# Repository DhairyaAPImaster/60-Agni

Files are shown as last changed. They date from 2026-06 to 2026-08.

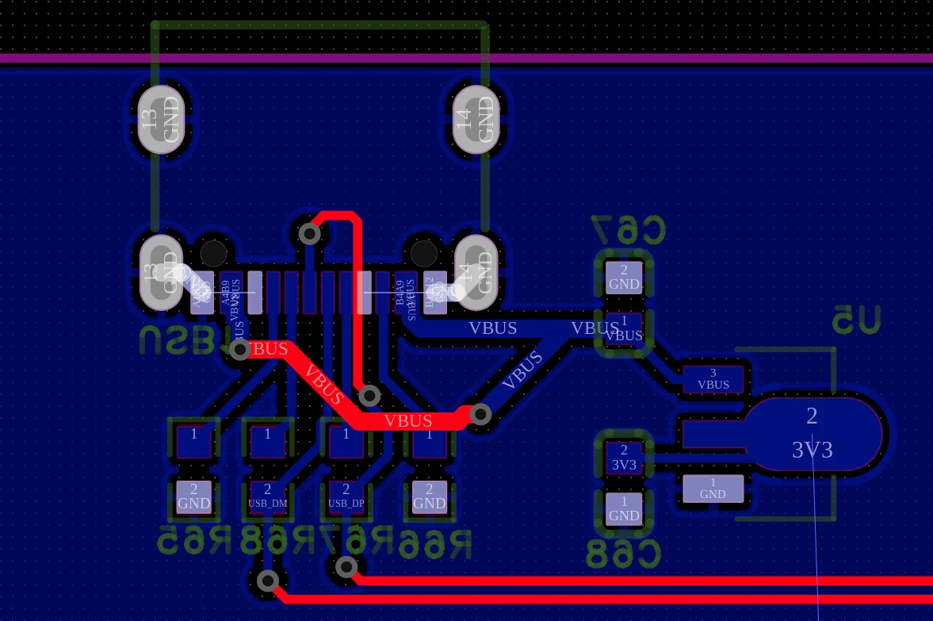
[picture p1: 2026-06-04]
Pics/image (3).webp

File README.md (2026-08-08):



***OSHWLAB Viewing link --->  https://oshwlab.com/dhairyak/project_nxljfiwq***

# Agni - the 60% keyboard
### by Dhairya

## About The Keyboard

**Agni is a custom 60% keyboard i have been working on for a few days. It is wired and connects to the laptop via USB-C. It also has an OLED on the top right corner to display data such as time, keyboard settings, etc.**

## Features 

- **60% default keyboard layout** - I chose this as it wouldf allow me to type easily and faster withought having to move my hand a lot.
- **Powered by a RP2040 at its core** - This runs the software required and allows the keyboard signals to be understood by the computer. It also runs the software to control the RGB lights and the OLED screen. 
- **Individual RGB lights for each Key** - So i added individual LED lights under each switch to give it better control to the lighting.

## Repo Structure 

- `src/` - source files for PCB and CAD
- `src/easyeda/` - EasyEDA source files
  - `src/easyeda/keyboard plate/` - src files for the keybard plate PCB
- `src/freecad/` - mechanical CAD sources
`production/` - **for fabrication outputs**
- `production/Keyboard plate PCB/` - PCB fabrication files for the keyboard plate
- `production/Main Keyboard PCB/` - PCB fabrication files for main keyboard PCB  (Gerbers, BOM, Pick & Place)
- `production/cad/` - 3D printing files
- `production/keyboard plate pcb/` -  Plate PCB Gerbers 
- `pics/` - images used in the README and documentation
- `firmware` - KMK firmware for the keyboard

## Schematic






## PCB 











## CAD





- ***Required 3d Printed part***



## How to replicate it (making it yourself) 

***Here are the steps to make this for yourself-***

- - ***ORDERING THE PCB***

- Step 1 - Basically Just Clone or downlaod this repo from github. U can do this by either going to the code button on this repo page and pressing download Zip or u can clone this Repo Or you can go to the Releases on this repo and download the Zip File there too (the fastest way to download is like just going to code and pressing download Zip Or by cloning the Repo.)

- Step 2 - In the the production folder you will find the CAD and PCB folders.
- Step 3 - The CAD folder contains all the 3d Pritnable files for the case of the keyboard. If you wish to u can make any changes to the design or make your own design and use that instead.
- Step 4 - The PCB folder contains the Gerbers, BOM , and CPL files. These are the files that allow you to get the PCB manufactured from JLCPCB (im using JLCPCB) or any other PCB manufacturer(like PCBway or others).
- Step 5 - Upload the gerbers zip file in JLCPCB "Place order / get instant quote" Page (u will need to sign up to order but can get a quote without signing up)
- Step 6 - Change the colour of the PCB in the options JLC gives (if u use JLC PCB most of the times canging colours does not add any charge acc to what i know)
- Step 7 - Select PCBA if u want JLCPCB to assemble the PCB for you but ngl soldering all components by hand is cheaper and saves u a ton of money and also is pretty fun (im hand soldering all components)
- Step 8 - Upload the CPL and BOM files whe JLCPCB asks u to.
- Step 9 - Recheck the position of all components (i faced no problem with this as all components were in the correct place but i have faced issues with the placement in one of my other projects i made in KiCAD)
- Step 10 - Add to cart and order the PCB!! **(if you are Hand soldering the components you will need to buy them from some other place i am using Robu.in as they have cheap components and a very vast library of components and they are cheaper than LCSC in india)**

- Step 11 - If you dont have a 3D PRINTER jlcpcb has a 3d printing service too caled JLC3DP so u can upload the files for the case there and get it printed too but if u have a 3d printer you can just print it youreslf and save a lot of money.

- - ***ORDERING THE KEYBOARD PLATE***

- Step 1 - In the `production/keyboard plate pcb/` folder u will find the gerbers for the Keyboard Plate
- Step 2 - Upload the gerbers to JLCPCB or any other manufacturer and order it after changing the colour if u want to make sure that the thickness is 1.6mm (if u are using any other manufacturer if possible choose 1.5mm thickness but 1.6 too is fine)
- ***NOTE -*** The gerbers in JLCPCB gerber viewer show just a single panel but that is bcs JLCPCB gerber viewer is shitty at showing slot regions however they are there and will be cut btw in the viewer if u zoom in u can see the space outline and a little gap btw the cutouts and the main board so yeah it shows as a single pannel due to JLCPCB's gerber viewer limitations. i checked in other gerber viewers and the holes are perfectly visible

- ***OTHER GERBER VIEWERS -***


<br/>
<br/>

- ***JLCPCB GERBER VEIWER-***

<br/>
<br/>

  -  **2d -**


<br/>
<br/>

  -  **3d -**


- Step 3 - **NOW TIME TO ASSEMBLE!!!!**

<br/>
<br/>
<br/>

- - ***Assembly***

- Step 1 - WAIT WAIT WAIT for your parts to be delivered
- Step 2 - Once you have all the parts (PCB, CASE and the componets if u are hand soldering the components) place the PCB in the Case (u will need to first hand solder the components if u are handsoldering it and if u chose economic PCBA then u will have to hand solder the switches too first)
- Step 3 - Now put the keyboard plate in the Case too and screw in the screws into the mounting holes in the case.
- Step 4 - Then use a cable to connect the OLED display to the pin headers for it on the main PCB and make sure it is secured properly. Then fit the OLED on the gap on the top part of the case which has the cutout for the OLED. (u might have to like get creative to fix the Oled to the hole but yeah i will just use a bit of hot glue and it should be fine or i might use the spacers that come with the screen if the spacers are tall enough)
- Step 5 - Once the PCB is secured inside the case glue Top Part of the Case shut (top header which has the screen cutout).
- Step 6 - Attatch the Keycaps on the switches...... and then --->
- Step 7 - **BOOM  THERE YOU GO U HAVE IT MADE!!!**

## BOM- Bill Of Materials

| # | Component | Qty | Unit Price (USD) | Subtotal (USD) | Source |
|---:|---|---:|---:|---:|---|
| 1 | Gateron G Pro 3.0 Black Switches | 7 | $1.99 | $13.90 | Meckeys |
| 2 | SK6812 MINI-E RGB LEDs | 200 pcs (1 pack) | $0.091/LED | $18.23 | Desertcart |
| 3 | ZORBES 130-Key Topographic Keycap Set | 1 | $10.50 | $10.50 | Amazon |
| 4 | Durock Plate Mount Stabilizers V3 (6.25U + 4×2U) | 1 set | $3.99 | $3.99 | GenesisPC |
| 5 | Raspberry Pi RP2040 MCU | 1 | $0.67 | $0.67 | Robu |
| 6 | Winbond W25Q16JWSNIQ 16-Mbit SPI NOR Flash | 1 | $3.31 | $3.31 | Robu |
| 7 | YXC YSX321SL 12 MHz Crystal, 12 pF | 1 | $0.21 | $0.21 | Robu |
| 8 | AMS1117-3.3V Voltage Regulator | 2 | $0.095 | $0.19 | Robu |
| 9 | USB-C 6-Pin Female SMD Connector | 2 | $0.63 | $1.26 | Robu |
| 10 | 0805 5.1 kΩ Resistor | 25 | $0.0049 | $0.12 | Robu |
| 11 | 1N4148W SOD-123 Switching Diode | 61 | $0.0150 | $0.92 | Robu |
| 12 | 6×6 mm SMD Tactile Switch | 5 | $0.0315 | $0.16 | Robu |
| 13 | 0805 100 nF X7R Capacitor | 75 | $0.0090 | $0.68 | Robu |
| 14 | 0805 15 pF C0G Capacitor | 37 | $0.0032 | $0.12 | Robu |
| 15 | 0805 10 µF X7R Capacitor | 5 | $0.0275 | $0.14 | Robu |
| 16 | 0805 4.7 kΩ Resistor | 30 | $0.0039 | $0.12 | Robu |
| 17 | 0805 5.1 kΩ Resistor | 10 | $0.0134 | $0.13 | Robu |
| 18 | 0805 10 kΩ Resistor | 3 | $0.0368 | $0.11 | Robu |
| 19 | 0805 100 Ω Resistor | 61 | $0.0086 | $0.53 | Robu |
| 20 | 0805 27 Ω Resistor | 60 | $0.0018 | $0.11 | Robu |
| 21 | 0.91" 128×32 I²C OLED Display | 1 | $1.59 | $1.59 | Robu |
| 22 | Agni Keyboard PCB | 5 | $3.62 | $18.10 | JLCPCB |
| 23 | Agni Keyboard Plate PCB | 5 | $3.00 | $15.00 | JLCPCB |

## Total Cost - 

***19.78USD <--> Tax + 90.09USD <--> Components (Passives+PCB's+Shipping+Switches+Stabalisers+Keycaps)
= 109.87 USD***

**Yeah this was expensive but would be like WAYYYYYY more expensive if i chose PCBA**

## License 
This project is licensed under the MIT License — see the [LICENSE](LICENSE) file for details.

## Credits 

***I used the following for making this project***

- ***EasyEDA*** - For PCB design
- ***FreeCAD*** - For designing the Case
- ***JLCPCB*** - Will be using to manufacture the PCB
- **[APX HUB by @Gabouin](https://github.com/Gabouin/APX-USB-HUB)** - Readme template

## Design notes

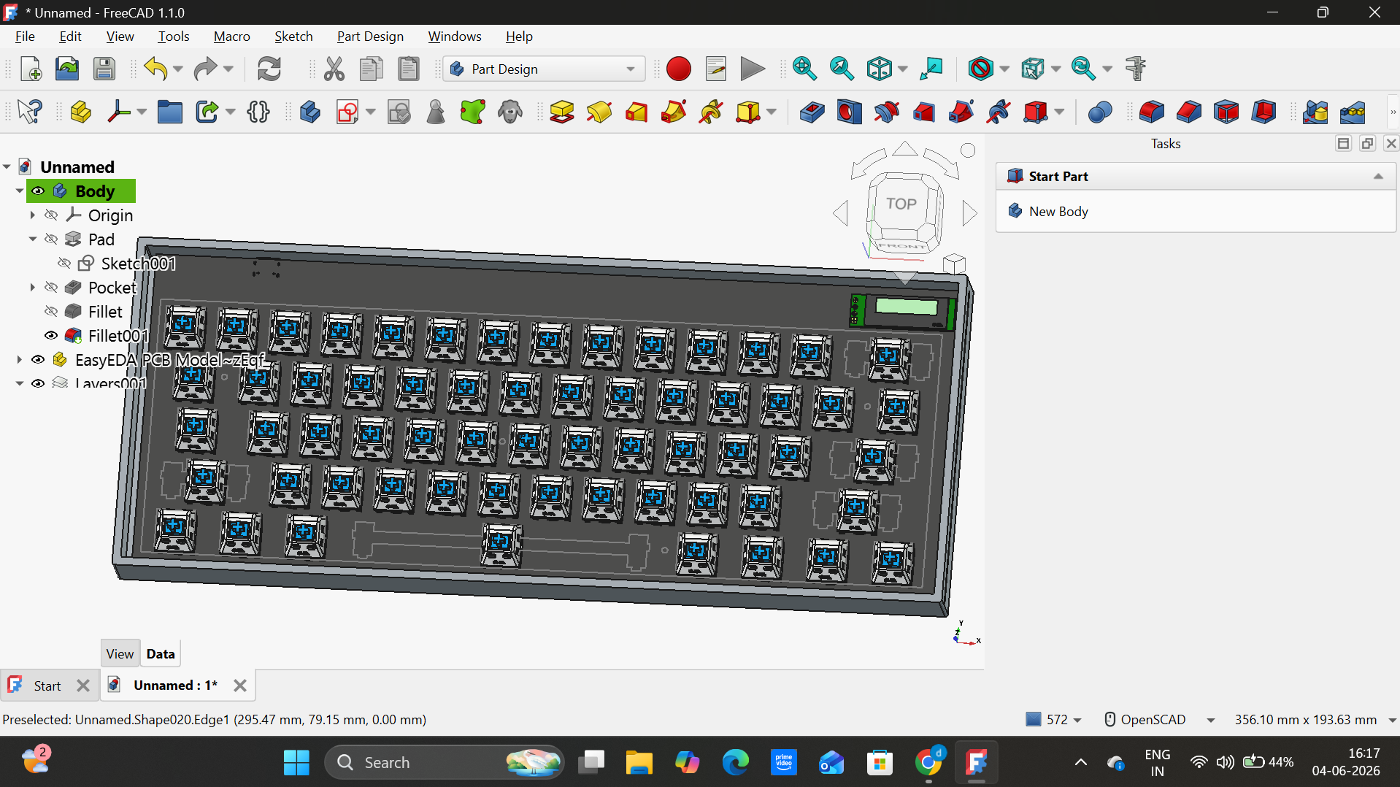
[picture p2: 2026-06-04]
Pics/Screenshot 2026-06-04 161731.png

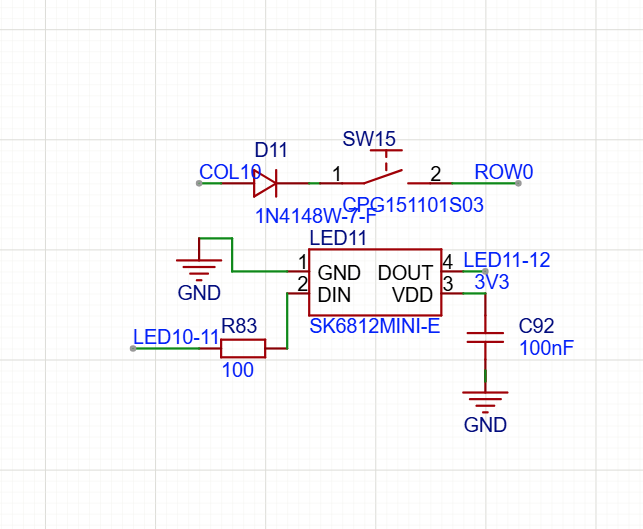
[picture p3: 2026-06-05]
Pics/Screenshot 2026-06-05 223801.png

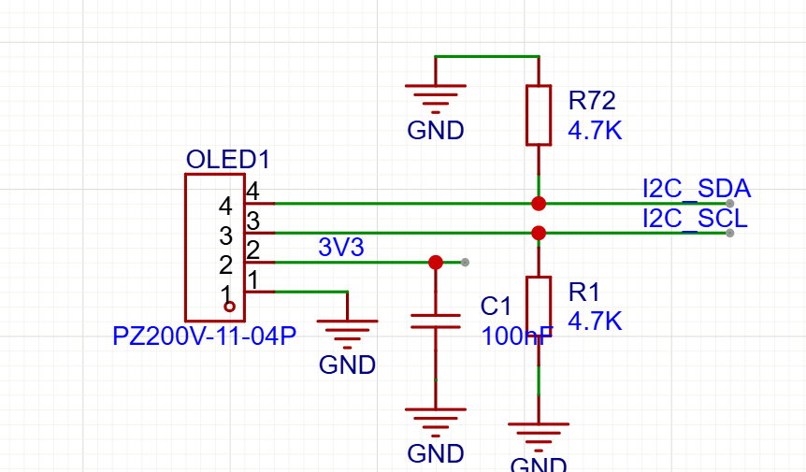
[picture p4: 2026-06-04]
Pics/Screenshot 2026-06-04 170409.png

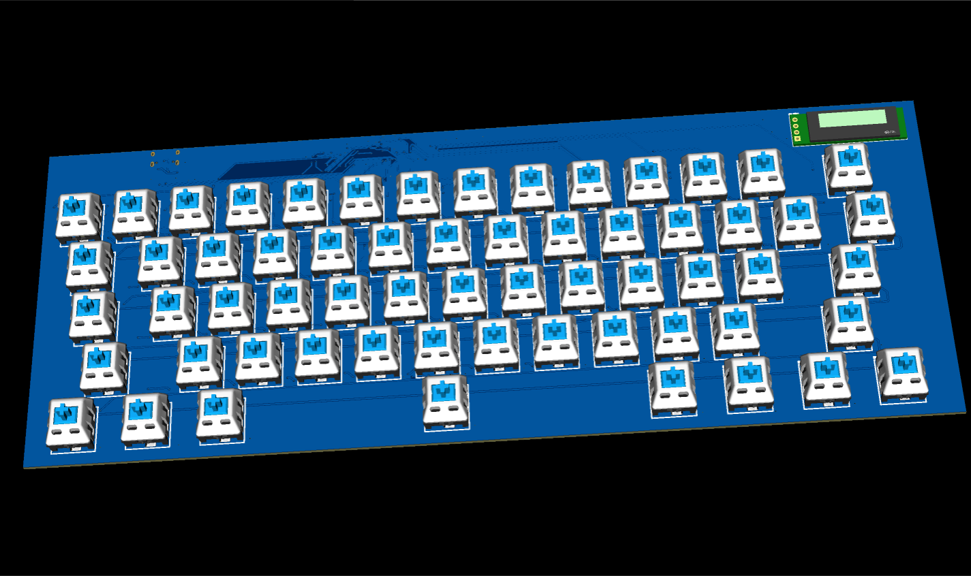
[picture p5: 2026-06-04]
Pics/Screenshot 2026-06-02 180203.png

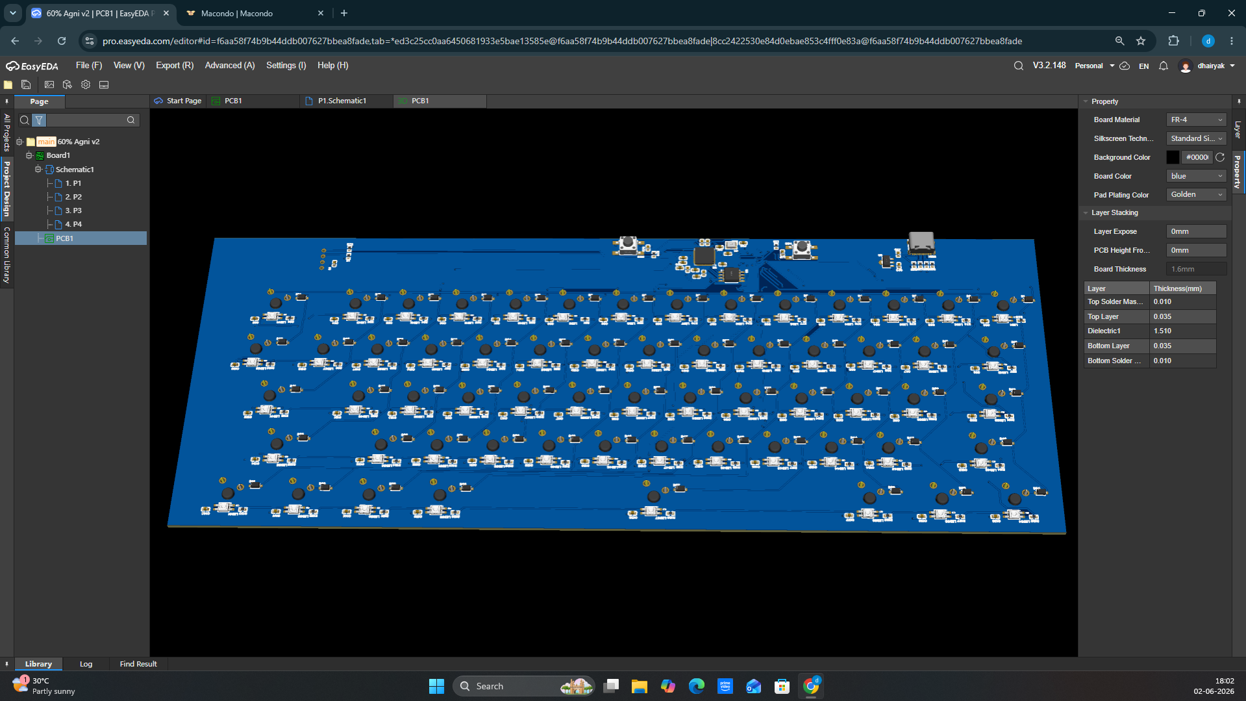
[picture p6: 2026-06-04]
Pics/Screenshot 2026-06-02 180218.png

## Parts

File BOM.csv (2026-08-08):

# | Component | Qty | Unit Price (USD) | Subtotal (USD) | Source
1 | Gateron G Pro 3.0 Black Switches | 7 | $1.99 | $13.90 | Meckeys
2 | SK6812 MINI-E RGB LEDs | 200 pcs (1 pack) | $0.091/LED | $18.23 | Desertcart
3 | ZORBES 130-Key Topographic Keycap Set | 1 | $10.50 | $10.50 | Amazon
4 | Durock Plate Mount Stabilizers V3 (6.25U + 4x2U) | 1 set | $3.99 | $3.99 | GenesisPC
5 | Raspberry Pi RP2040 MCU | 1 | $0.67 | $0.67 | Robu
6 | Winbond W25Q16JWSNIQ 16-Mbit SPI NOR Flash | 1 | $3.31 | $3.31 | Robu
7 | YXC YSX321SL 12 MHz Crystal 12 pF | 1 | $0.21 | $0.21 | Robu
8 | AMS1117-3.3V Voltage Regulator | 2 | $0.095 | $0.19 | Robu
9 | USB-C 6-Pin Female SMD Connector | 2 | $0.63 | $1.26 | Robu
10 | 0805 5.1 kOhm Resistor | 25 | $0.0049 | $0.12 | Robu
11 | 1N4148W SOD-123 Switching Diode | 61 | $0.0150 | $0.92 | Robu
12 | 6x6 mm SMD Tactile Switch | 5 | $0.0315 | $0.16 | Robu
13 | 0805 100 nF X7R Capacitor | 75 | $0.0090 | $0.68 | Robu
14 | 0805 15 pF C0G Capacitor | 37 | $0.0032 | $0.12 | Robu
15 | 0805 10 uF X7R Capacitor | 5 | $0.0275 | $0.14 | Robu
16 | 0805 4.7 kOhm Resistor | 30 | $0.0039 | $0.12 | Robu
17 | 0805 5.1 kOhm Resistor | 10 | $0.0134 | $0.13 | Robu
18 | 0805 10 kOhm Resistor | 3 | $0.0368 | $0.11 | Robu
19 | 0805 100 Ohm Resistor | 61 | $0.0086 | $0.53 | Robu
20 | 0805 27 Ohm Resistor | 60 | $0.0018 | $0.11 | Robu
21 | 0.91" 128x32 I2C OLED Display | 1 | $1.59 | $1.59 | Robu
22 | Agni Keyboard PCB | 5 | $3.62 | $18.10 | JLCPCB
23 | Agni Keyboard Plate PCB | 5 | $3.00 | $15.00 | JLCPCB
 |  |  |  | Components Subtotal | $90.09
 |  |  |  | Tax | $19.78
 |  |  |  | Total | $109.87

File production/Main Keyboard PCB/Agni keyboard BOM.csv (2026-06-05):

No. | Quantity | Comment | Designator | Footprint | Value | Manufacturer Part | Manufacturer | Supplier Part | Supplier
1 | 75 | 100nF | C1,C70,C71,C72,C73,C74,C75,C76,C77,C78,C79,C80,C81,C82,C83,C84,C85,C86,C87,C88,C89,C90,C91,C92,C93,C94,C95,C96,C97,C98,C99,C100,C101,C102,C103,C104,C105,C106,C107,C108,C109,C110,C111,C112,C113,C114,C115,C116,C117,C118,C119,C120,C121,C122,C123,C124,C125,C126,C127,C128,C129,C130,C131,C132,C133,C134,C135,C136,C137,C138,C139,C140,C141,C142,C143 | C0805 | 100nF
2 | 2 | 15pF | C65,C66 | C0805 | 15pF
3 | 2 | 10uF | C67,C68 | C0805 | 10uF
4 | 61 | 1N4148W-7-F | D1,D2,D3,D4,D5,D6,D7,D8,D9,D10,D11,D12,D13,D14,D15,D16,D17,D18,D19,D20,D21,D22,D23,D24,D25,D26,D27,D28,D29,D30,D31,D32,D33,D34,D35,D36,D37,D38,D39,D40,D41,D42,D43,D44,D45,D46,D47,D48,D49,D50,D51,D52,D53,D54,D55,D56,D57,D58,D59,D60,D61 | SOD-123_L2.7-W1.6-LS3.7-RD-1 |  | 1N4148W-7-F | DIODES(美台) | C83528 | LCSC
5 | 61 | SK6812MINI-E | LED1,LED2,LED3,LED4,LED5,LED6,LED7,LED8,LED9,LED10,LED11,LED12,LED13,LED14,LED15,LED16,LED17,LED18,LED19,LED20,LED21,LED22,LED23,LED24,LED25,LED26,LED27,LED28,LED29,LED30,LED31,LED32,LED33,LED34,LED35,LED36,LED37,LED38,LED39,LED40,LED41,LED42,LED43,LED44,LED45,LED46,LED47,LED48,LED49,LED50,LED51,LED52,LED53,LED54,LED55,LED56,LED57,LED58,LED59,LED60,LED61 | LED-SMD_4P-L3.2-W2.8-LS5.9_SK6812MINI-E |  | SK6812MINI-E | 欧思科光电 | C5149201 | LCSC
6 | 1 | PZ200V-11-04P | OLED1 | HDR-TH_4P-P2.00-V-M |  | PZ200V-11-04P | XFCN(兴飞) | C541858 | LCSC
7 | 2 | 4.7K | R1,R72 | R0805 | 4.7K
8 | 2 | 5.1K | R65,R66 | R0805 | 5.1K
9 | 2 | 27ohm | R67,R68 | R0805 | 27ohm
10 | 2 | 10K | R70,R71 | R0805 | 10K
11 | 61 | 100 | R73,R74,R75,R76,R77,R78,R79,R80,R81,R82,R83,R84,R85,R86,R87,R88,R89,R90,R91,R92,R93,R94,R95,R96,R97,R98,R99,R100,R101,R102,R103,R104,R105,R106,R107,R108,R109,R110,R111,R112,R113,R114,R115,R116,R117,R118,R119,R120,R121,R122,R123,R124,R125,R126,R127,R128,R129,R130,R131,R132,R133 | R0805 | 100
12 | 2 | KH-6X6X5H-STM | SW3,SW4 | SW-SMD_4P-L6.0-W6.0-P4.50-LS9.0_H5.0 |  | KH-6X6X5H-STM | kinghelm(金航标) | C2837531 | LCSC
13 | 61 | CPG151101S03 | SW5,SW6,SW7,SW8,SW9,SW10,SW11,SW12,SW13,SW14,SW15,SW16,SW17,SW18,SW19,SW20,SW21,SW22,SW23,SW24,SW25,SW26,SW27,SW28,SW29,SW30,SW31,SW32,SW33,SW34,SW35,SW36,SW37,SW38,SW39,SW40,SW41,SW42,SW43,SW44,SW45,SW46,SW47,SW48,SW49,SW50,SW51,SW52,SW53,SW54,SW55,SW56,SW57,SW58,SW59,SW60,SW61,SW62,SW63,SW64,SW65 | KEY-TH_CPG1511F01S0X |  | CPG151101S03 | Kailh(凯华) | C404350 | LCSC
14 | 1 | RP2040 | U2 | LQFN-56_L7.0-W7.0-P0.4-EP |  | RP2040 | Raspberry Pi(树莓派) | C2040 | LCSC
15 | 1 | W25Q16JVSSIQ | U3 | SOIC-8_L5.3-W5.3-P1.27-LS8.0-BL |  | W25Q16JVSSIQ | Winbond(华邦) | C131025 | LCSC
16 | 1 | 12MHz | U4 | CRYSTAL-SMD_4P-L3.2-W2.5-BL | 12MHz | ABM8-272-T3 | ABRACON | C20625731 | LCSC
17 | 1 | AMS1117-3.3 | U5 | SOT-89-3_L4.5-W2.5-P1.50-LS4.2-BR |  | AMS1117-3.3 | GOODWORK(固得沃克) | C6067465 | LCSC
18 | 1 | TYPE-C 16PIN 2MD(073) | USB1 | USB-C-SMD_TYPE-C-16PIN-2MD-073 |  | TYPE-C 16PIN 2MD(073) | SHOU HAN(首韩) | C2765186 | LCSC

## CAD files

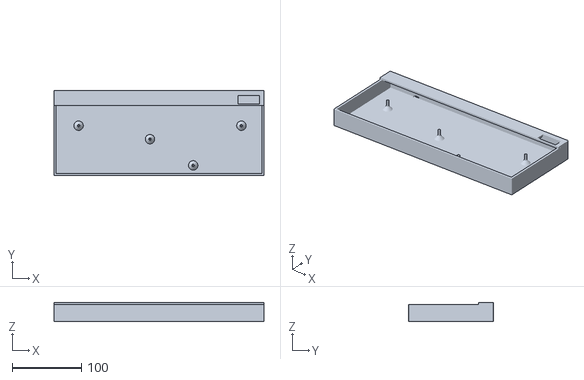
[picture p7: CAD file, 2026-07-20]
production/CAD (keyboard case)/Full Case (including top plate).stl
303.0 x 123.1 x 28.0

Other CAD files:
production/CAD (keyboard case)/Main Case.step
assembly.step
PCB.step
src/EasyEDA/PCB.step
production/CAD (keyboard case)/Top Plate of the case.step
production/CAD (keyboard case)/Main Case.stl
production/CAD (keyboard case)/Top Plate of the case.stl

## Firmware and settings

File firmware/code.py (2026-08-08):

import board
import busio
from kmk.kmk_keyboard import KMKKeyboard
from kmk.keys import KC
from kmk.scanners import DiodeOrientation
from kmk.modules import Module
from kmk.modules.layers import Layers
from kmk.modules.rgb import RGB, AnimationModes

keyboard = KMKKeyboard()

# ---- Matrix pins ----
keyboard.col_pins = (
    board.GP6, board.GP7, board.GP8, board.GP9, board.GP10,
    board.GP11, board.GP12, board.GP13, board.GP14, board.GP15,
    board.GP16, board.GP17, board.GP18, board.GP19,
)
keyboard.row_pins = (
    board.GP1, board.GP2, board.GP3, board.GP4, board.GP5,
)
keyboard.diode_orientation = DiodeOrientation.COL2ROW

keyboard.modules.append(Layers())

NUM_PIXELS = 61
rgb = RGB(
    pixel_pin=board.GP22,
    num_pixels=NUM_PIXELS,
    val_limit=100,
    hue_default=0,
    sat_default=100,
    val_default=80,
    animation_mode=AnimationModes.STATIC,
)
keyboard.modules.append(rgb)

try:
    import adafruit_ssd1306

    i2c = busio.I2C(scl=board.GP21, sda=board.GP20)
    oled = adafruit_ssd1306.SSD1306_I2C(128, 32, i2c)

    class OLEDStatus(Module):
        """Minimal status display: shows current layer name."""

        def __init__(self, display):
            self.display = display
            self._last_layer = None

        def during_bootup(self, keyboard):
            self.display.fill(0)
            self.display.text('Agni V2', 0, 0, 1)
            self.display.text('Ready', 0, 12, 1)
            self.display.show()
            return keyboard

        def before_matrix_scan(self, keyboard):
            return keyboard

        def after_matrix_scan(self, keyboard):
            active = keyboard.active_layers[0] if keyboard.active_layers else 0
            if active != self._last_layer:
                self._last_layer = active
                self.display.fill(0)
                self.display.text('Agni V2', 0, 0, 1)
                label = 'Base' if active == 0 else 'Fn (L{})'.format(active)
                self.display.text(label, 0, 12, 1)
                self.display.show()
            return keyboard

        def process_key(self, keyboard, key, is_pressed, int_coord):
            return key

        def before_hid_send(self, keyboard):
            return keyboard

        def after_hid_send(self, keyboard):
            return keyboard

        def on_powersave_enable(self, keyboard):
            return keyboard

        def on_powersave_disable(self, keyboard):
            return keyboard

    keyboard.modules.append(OLEDStatus(oled))
except Exception as e:  # noqa: BLE001
    print('OLED init failed:', e)

_______ = KC.TRNS
XXXXXXX = KC.NO
keymap = [
    [
        # Row 0
        KC.ESC,  KC.N1,   KC.N2,   KC.N3,  KC.N4,  KC.N5,  KC.N6,
        KC.N7,   KC.N8,   KC.N9,   KC.N0,  KC.MINS, KC.EQL, KC.BSPC,
        # Row 1
        KC.TAB,  KC.Q,    KC.W,    KC.E,   KC.R,   KC.T,   KC.Y,
        KC.U,    KC.I,    KC.O,    KC.P,   KC.LBRC, KC.RBRC, KC.BSLS,
        # Row 2
        KC.CAPS, KC.A,    KC.S,    KC.D,   KC.F,   KC.G,   KC.H,
        KC.J,    KC.K,    KC.L,    KC.SCLN, KC.QUOT, KC.ENT, XXXXXXX,
        # Row 3
        KC.LSFT, KC.Z,    KC.X,    KC.C,   KC.V,   KC.B,   KC.N,
        KC.M,    KC.COMM, KC.DOT,  KC.SLSH, KC.RSFT, XXXXXXX, XXXXXXX,
        # Row 4
        KC.LCTL, KC.LGUI, KC.LALT, KC.SPC, KC.MO(1), KC.RALT, KC.RGUI,
        KC.RCTL, XXXXXXX, XXXXXXX, XXXXXXX, XXXXXXX, XXXXXXX, XXXXXXX,
    ],
    [
        # Layer 1: Fn layer - function keys, media, RGB controls
        KC.GRV,  KC.F1,   KC.F2,   KC.F3,  KC.F4,  KC.F5,  KC.F6,
        KC.F7,   KC.F8,   KC.F9,   KC.F10, KC.F11, KC.F12, KC.DEL,
        _______, _______, _______, _______, _______, _______, _______,
        _______, _______, KC.PSCR, KC.HOME, KC.END, KC.INS, _______,
        _______, _______, _______, _______, _______, _______, _______,
        _______, _______, _______, KC.PGUP, _______, KC.ENT, XXXXXXX,
        _______, _______, _______, _______, KC.LEFT, KC.DOWN, KC.UP,
        KC.RGHT, _______, _______, KC.PGDN, _______, XXXXXXX, XXXXXXX,
        _______, _______, _______, _______, _______, _______, _______,
        _______, XXXXXXX, XXXXXXX, XXXXXXX, XXXXXXX, XXXXXXX, XXXXXXX,
    ],
]

keyboard.keymap = keymap

if __name__ == '__main__':
    keyboard.go()

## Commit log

2026-06-04 Initial commit - Complete 60% Keyboard PCB and Case
    [Agni Keyboad BOM.csv, Main Case.step, Top Plate.step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]
2026-06-05 Update README with additional images and sections
    Added images for schematic, PCB, CAD, and required 3D printed parts.
2026-06-05 Update README with additional PCB images
    Added new images to the PCB section of the README.
2026-06-05 Rearanged the folder structure, added revised fabrication and scr files for PCB due to changes in components
    [Agni Keyboad BOM.csv, Agni keyboard BOM.csv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]
2026-06-06 Document replication steps in README
    Added detailed steps for replicating the project, including instructions for downloading files, manufacturing PCBs, and assembling components.
2026-06-06 Enhance README with ordering and assembly instructions
    Updated the README with detailed steps for ordering PCBs and keyboard plates, assembly instructions, and added images for clarity.
2026-06-06 Enhance README with gerber viewer details and images
    Updated README with additional notes on gerber viewer limitations and images.
2026-06-06 Update README with formatting
    Corrected formatting and improved clarity in the README regarding gerber viewer limitations and assembly steps.
2026-06-07 Fixed the issue with the keyboard plate and added final gerbers and src files for it.
2026-06-09 added the gerbers for the keyboard plate in correct folder along with its src file
    [Agni keyboard BOM.csv, Main Case.step, Top Plate.step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]
2026-06-23 Added a banner to the readme, added an assembly.glb file
2026-06-23 FInally figured out how to add an assembly.Step File without git push failing due to size
    [AgniV2 Keyboard.step, AgniV2 KeyboardPCB.step, Main Case.step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]
2026-06-23 added an assembly.step file in a zip folder to be able to push it due to its size
    [asssembly.step]
2026-06-23 Track all step files with wildcard and purge history
    [assembly.step]
2026-06-23 remvoed the assembly.zip folder now that the individual assmebly file has been pushed to the repo!!!
2026-07-20 added stl files
    [Agni keyboard BOM.csv, AgniV2 Keyboard.step, AgniV2 KeyboardPCB.step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]
2026-08-08 added a bom.csv file in root diectory
    [BOM.csv]
2026-10-20 transfered the assembly to the CAD folder under production folder
2026-10-20 made a normal CAD folder and a CAD to 3d print folder
2026-10-20 Update section title from 'Renders' to 'Renders and CAD'
2026-10-20 Fix image tags and update BOM section formatting
    Updated image tags in README for better display.
2026-10-20 updated the BOM
